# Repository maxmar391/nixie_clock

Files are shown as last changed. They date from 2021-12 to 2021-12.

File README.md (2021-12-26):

# LED nixie clock with Arduino

## Description
This repository is about a nixie clock based on an Arduino Nano board, an RTC module, and some LED nixie boards. The Arduino Nan

## Bill of materials
* Arduino Nano
The small version of the Arduino family to keep the electronics part small and discreet. The Arduino board reads the clock from the real time clock module and controls the LEDs accordingly. The code contains color changes every full hour. 
* [DS3231 Real time clock (RTS) module](https://www.banggood.com/DS3231-AT24C32-IIC-Precision-RTC-Real-Time-Clock-Memory-Module-p-1547989.html)<br>
This module is powered by a battery, equipped with a quartz oscillator, and maintains the clock even after being cut off from power. By doing so, the LED clock will not lose the information of the current time, even after plugged out from electricity.
* CR2032 battery
* 4x [LED nixie boards](https://www.led-genial.de/LED-Nixie-M-Einzelmodul-Bausatz) <br>
with 20 LEDs each(2 LEDs per digit and ten digits)
* 220 ohm resistor
The resistor should be inserted between the Arduino Nano and the LED boards to limit the current on the wire carrying the control signal.
* 100 nF capacitor <br>
This capacitor stabilizes the power supply and prevents the LEDs from flickering or dimming, when the digits are shifting and the dragged current is changing considerably. Since the LEDs switch quickly, a smaller capacitor might also do the job. Depending on your board and power supply, a capacitor might not be necessary whatsoever.
* Dupont jumper wires
similar to wires like these: https://de.aliexpress.com/item/4000203371860.html

## Libraries
* DS3231.h
This library should be manually downloaded and added to the working directory of the Arduino IDE. More information and the zip file for download available at http://www.rinkydinkelectronics.com/library.php?id=73 
* Adafruit_NeoPixel.h
This library can be directly installed from the library manager of the Arduino IDE. More information available at https://github.com/adafruit/Adafruit_NeoPixel 

## Data sheets
* [DS3231 Real time clock (RTS) module](https://datasheets.maximintegrated.com/en/ds/DS3231.pdf)

## Wiring
The wiring is shown in the following two pictures (schematic view and breadboard view).

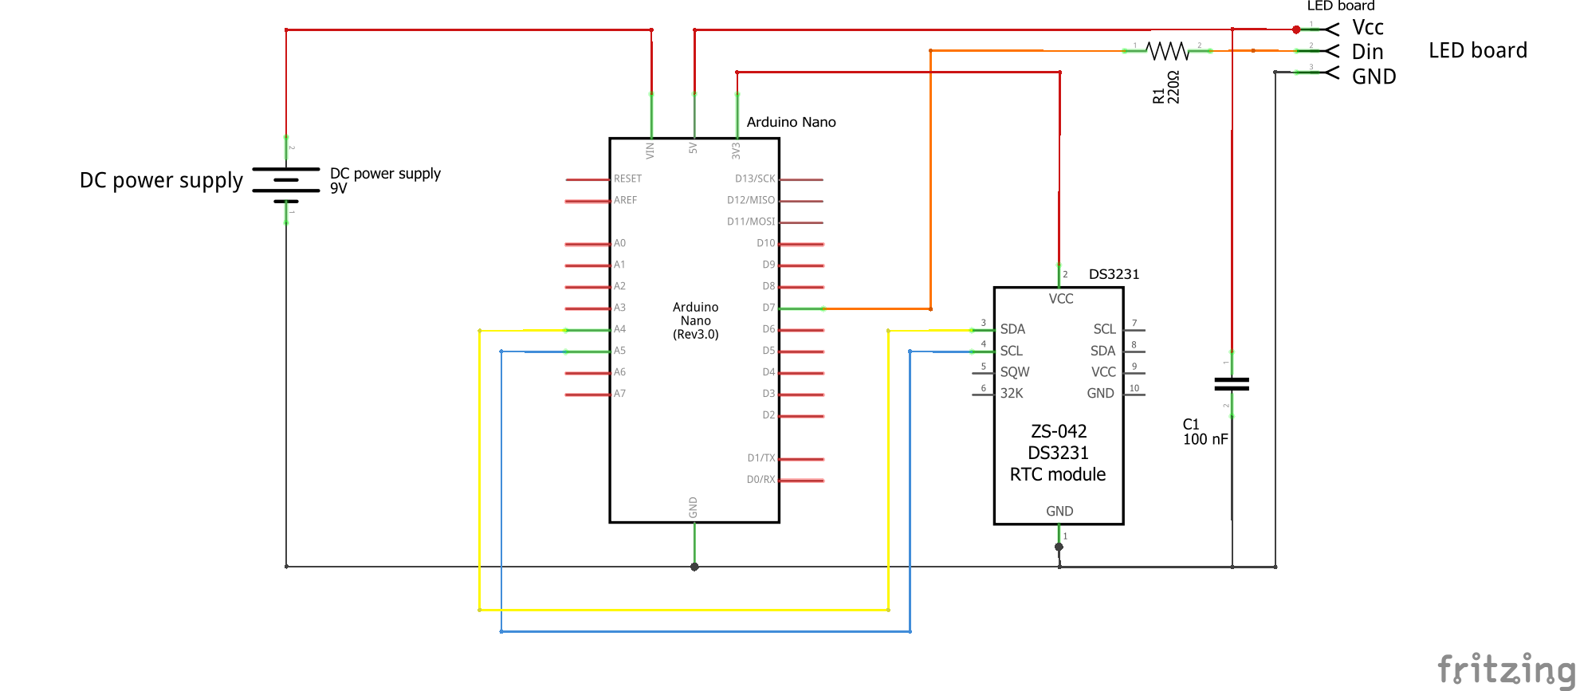
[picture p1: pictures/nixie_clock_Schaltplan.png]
Schematic view


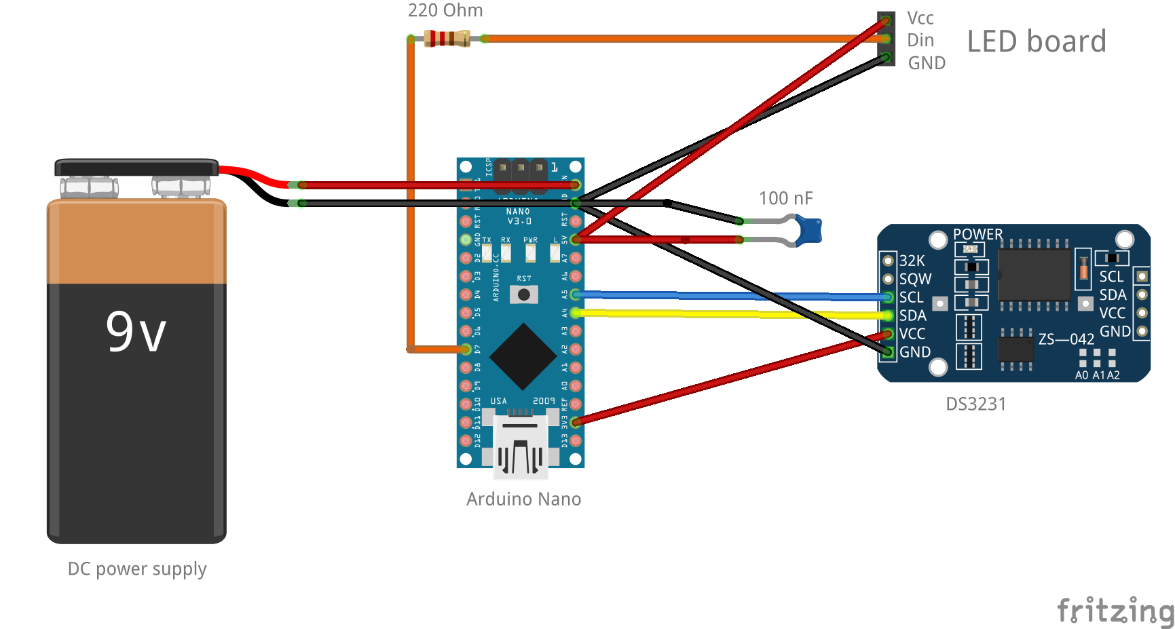
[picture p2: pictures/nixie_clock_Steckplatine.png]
Breadboard view


## References
Please find some references and related material for further reading below.

* https://create.arduino.cc/projecthub/MisterBotBreak/how-to-use-a-real-time-clock-module-ds3231-bc90fe
* https://www.heise.de/select/make/2018/4/1535076681386192 

## Impressions
Some impressions of the final LED nixie clock.

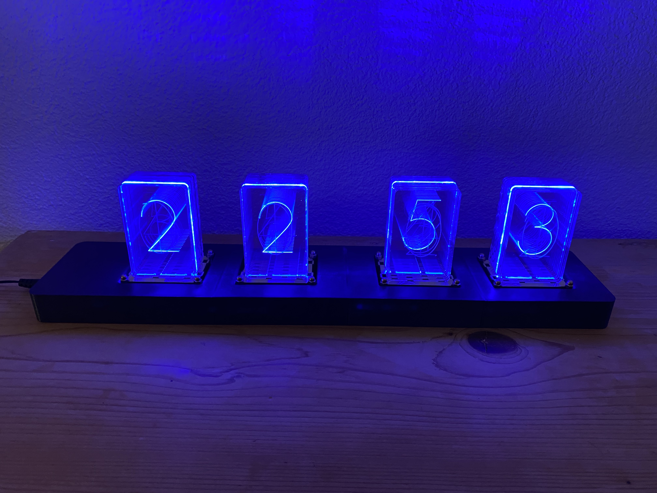
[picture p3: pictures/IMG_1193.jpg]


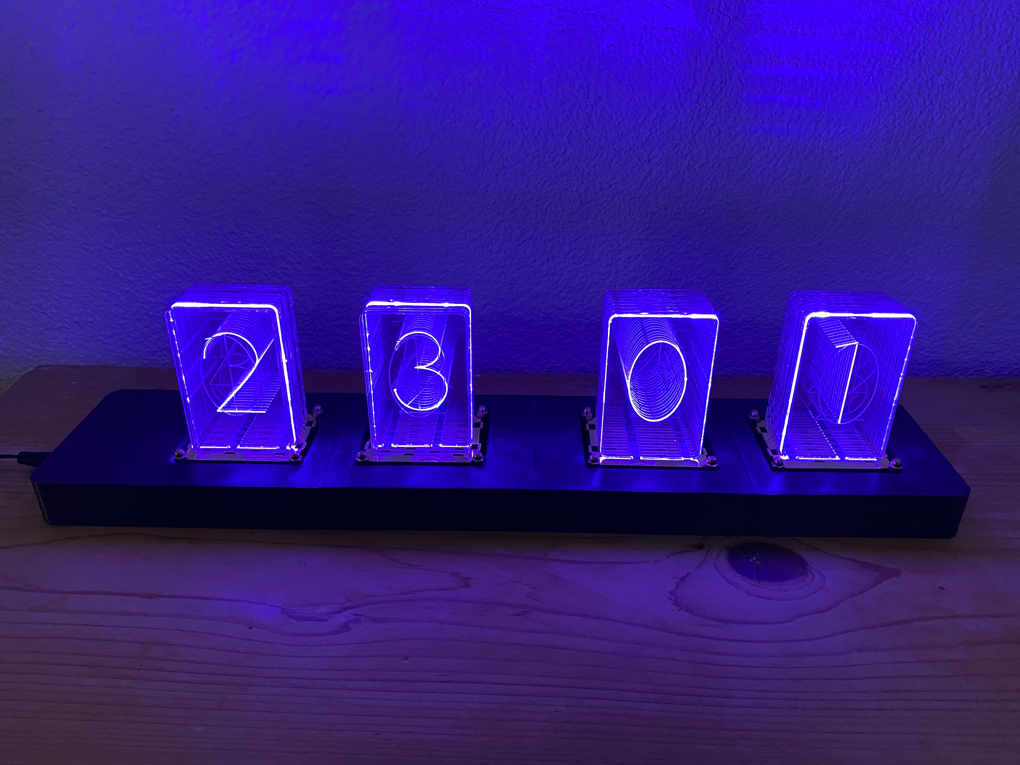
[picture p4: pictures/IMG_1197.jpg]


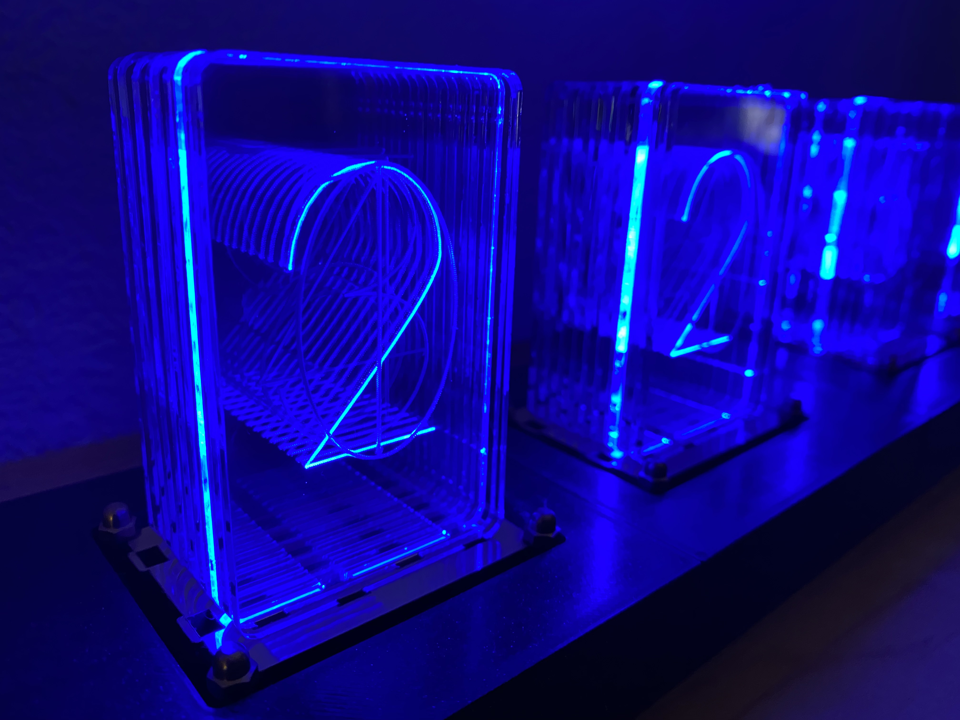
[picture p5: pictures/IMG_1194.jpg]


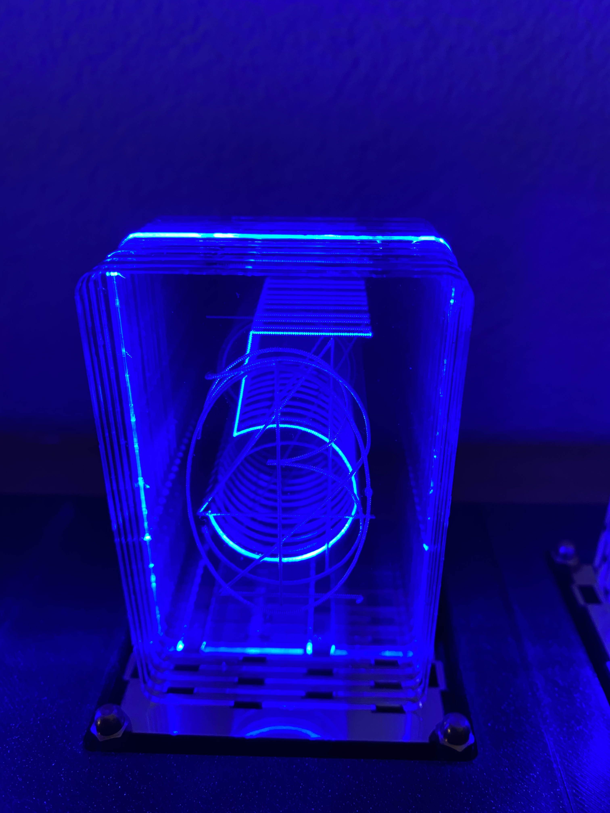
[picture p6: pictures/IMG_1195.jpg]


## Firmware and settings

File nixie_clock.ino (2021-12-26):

 //libraries
#include <Adafruit_NeoPixel.h>    // https://github.com/adafruit/Adafruit_NeoPixel
#include <DS3231.h>               // http://www.rinkydinkelectronics.com/library.php?id=73    ACHTUNG: Dies ist NICHT die Bibliothek, die ueber den Bibliotheksverwalter eingebunden werden kann! Ggf. vorher die andere Bibliothek entfernen oder lokalen Speicherort angeben ("")


// uint8_t = 8 unsigned bits, cross-platform data type
const int PIN = 7;       // data pin (insert 220 ohm resistor!)
const int DIGITS = 4;    // number of digits

int tens;
int mappedTens;
int ones;
int mappedOnes;


// Declare NeoPixel strip object
Adafruit_NeoPixel pixels = Adafruit_NeoPixel(DIGITS * 20, PIN, NEO_GRB + NEO_KHZ800);
// Argument 1 = Number of pixels in NeoPixel strip
// Argument 2 = Arduino pin number (most are valid)
// Argument 3 = Pixel type flags, add together as needed:
//   NEO_KHZ800  800 KHz bitstream (most NeoPixel products w/WS2812 LEDs)
//   NEO_KHZ400  400 KHz (classic 'v1' (not v2) FLORA pixels, WS2811 drivers)
//   NEO_GRB     Pixels are wired for GRB bitstream (most NeoPixel products)
//   NEO_RGB     Pixels are wired for RGB bitstream (v1 FLORA pixels, not v2)
//   NEO_RGBW    Pixels are wired for RGBW bitstream (NeoPixel RGBW products)

// definition of RGB structure with three properties
struct RGB {
  int red;
  int green;
  int blue;
};


//******************************************************************
// function to map the time input values to the correct pixels
int Mapping (int value) {

  switch (value) {
    case 0: return 5;
    case 1: return 0;
    case 2: return 6;
    case 3: return 1;
    case 4: return 7;
    case 5: return 2;
    case 6: return 8;
    case 7: return 3;
    case 8: return 9;
    case 9: return 4;
  }
}


// function to display the hours in the pixels
void DisplayHours (int hours, struct RGB* farbe) {

  tens = (int)(hours / 10);     // Extract first digit from input value by using division by 10 and convert it to integer
  mappedTens = Mapping(tens);

  ones = (int)(hours % 10);     // Extract second digit from input by using modulo 10 function and convert it to integer
  mappedOnes = Mapping(ones);

  pixels.setPixelColor(mappedTens, pixels.Color (farbe->red, farbe->green, farbe->blue));
  pixels.setPixelColor(mappedOnes + 10, pixels.Color (farbe->red, farbe->green, farbe->blue));
}


// function to display the minutes in the pixels
void DisplayMinutes (int minutes, struct RGB* farbe) {

  tens = (int)(minutes / 10);   // Extract first digit from input value by using division by 10 and convert it to integer
  mappedTens = Mapping(tens);

  ones = (int)(minutes % 10);   // Extract second digit from input by using modulo 10 function and convert it to integer
  mappedOnes = Mapping(ones);

  pixels.setPixelColor(mappedTens + 20, pixels.Color (farbe->red, farbe->green, farbe->blue));
  pixels.setPixelColor(mappedOnes + 30, pixels.Color (farbe->red, farbe->green, farbe->blue));
}




//******************************************************************
// SETUP
void setup() 
{
  // Initialize output pin
  pinMode(PIN, OUTPUT);

  // Initialize serial monitor
  Serial.begin(9600);           // open serial port with 9600 baud rate

  // Initialize pixels
  pixels.begin();               // Initialize the pixel array
  pixels.clear();               // Turn all pixels off
  pixels.setBrightness(255);    // Set brightness of pixels

}

//******************************************************************
// LOOP
void loop() 
{
  // Create RGB structure here, otherwise the variable "farbe" is not recognized in the loop
  RGB farbe;

  // Initialize time module here, otherwise the "time" variable is not recognized in the loop
  DS3231  rtc(SDA, SCL);      // Initialize the DS3231 time module using the hardware interface
  Time zeit;          // Define variable for storing the time
  rtc.begin();                // Initialize the time module

  //rtc.setTime(20, 58, 0);      // Set time module to 12:00:00 (24 hours format)


  while (1) // create artifical loop
  {
    zeit = rtc.getTime();     // read time

    Serial.print(zeit.hour);  // print hours
    Serial.print(":");        // print separator
    Serial.print(zeit.min);   // print minutes
    Serial.println();         // print new line


    switch (zeit.hour % 6) // Calculate hours modulo 6 to define one out of six colors, color changes thus every full hour
	{ 
      case 0: // red
        farbe.red = 255;
        farbe.green = 0;
        farbe.blue = 0;
        break;
      case 1: // yellow
        farbe.red = 255;
        farbe.green = 200;
        farbe.blue = 0;
        break;
      case 2: // green
        farbe.red = 0;
        farbe.green = 255;
        farbe.blue = 0;
        break;
      case 3:  // turqouise
        farbe.red = 0;
        farbe.green = 255;
        farbe.blue = 200;
        break;
      case 4: // blue
        farbe.red = 0;
        farbe.green = 0;
        farbe.blue = 255;
        break;
      case 5: // purple
        farbe.red = 136;
        farbe.green = 0;
        farbe.blue = 255;
        break;
    }

    pixels.clear();                     // Clear the pixels
    pixels.setBrightness(255);          // Set brightness of pixels
    DisplayHours(zeit.hour, &farbe);    // Send the digits for hours to the pixels
    DisplayMinutes(zeit.min, &farbe);   // Send the digits for minutes to the pixels
    pixels.show();                      // Show the digits in the pixels

    delay(10000);                       // wait for 10 seconds
  }
}

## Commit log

2020-11-24 initially created the Arduino file and changed the readme
2020-11-25 added original CAD files from SolidEdge (.par)
    [LED_Nixie.cfg]
2021-12-26 added breadboard and schematic views
    [LED_Nixie.cfg, nixie_clock.fzz]
2021-12-26 changed breadboard and schematic views
    [nixie_clock.fzz]
